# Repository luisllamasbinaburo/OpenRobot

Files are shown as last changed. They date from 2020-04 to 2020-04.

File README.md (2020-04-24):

# OpenRobot

OpenRobot is an Open Hardware PCB based on Arduino Nano, especially designed for teaching technology

Once assembled, you can use make multiple projects and robots without welding, just adding or removing components in the dupont headers.

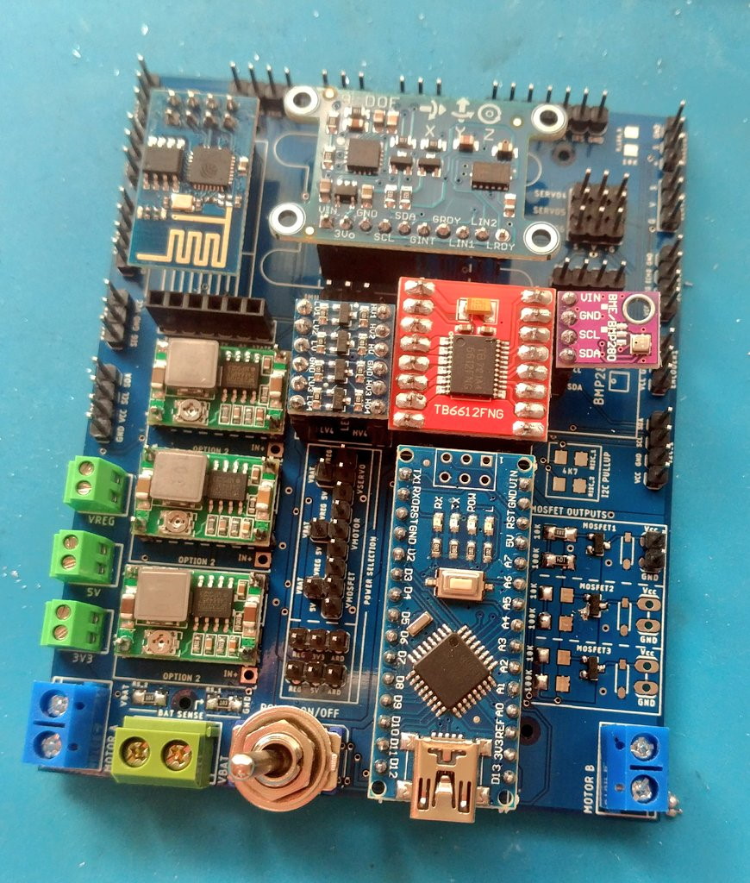
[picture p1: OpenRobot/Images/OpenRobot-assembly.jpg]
Assembly


OpenRobot is compatible with a huge number of modules thanks to the multiple outputs. 
Also, is compatible with several DC Converters, and differents IMUs (MPU6050, MPU9050/9250 and L3GD20)

## What can I make with OpenRobot?
Almost any Arduino project you can ever imagine! 

Some of them,
- DC Motors Robot, like obstacle avoider (ultrasonic or Sharp), line follower, self-balancing bot...
- Servo Motor Robot, like 2-DOF Tower, 6-DOF Arms...
- Mosfet output for high current proyects (LED, electromagnets, water pumps)
- Bluetooth projects (HC-05/HC-06), like Android or PC communication, beacons...
- WiFi projects (ESP01), like controlling from Web, MQTT datalogger...
- Temperature, pressure, humidity weather station with BME280
- Any other project, thanks to the multiple available outputs!

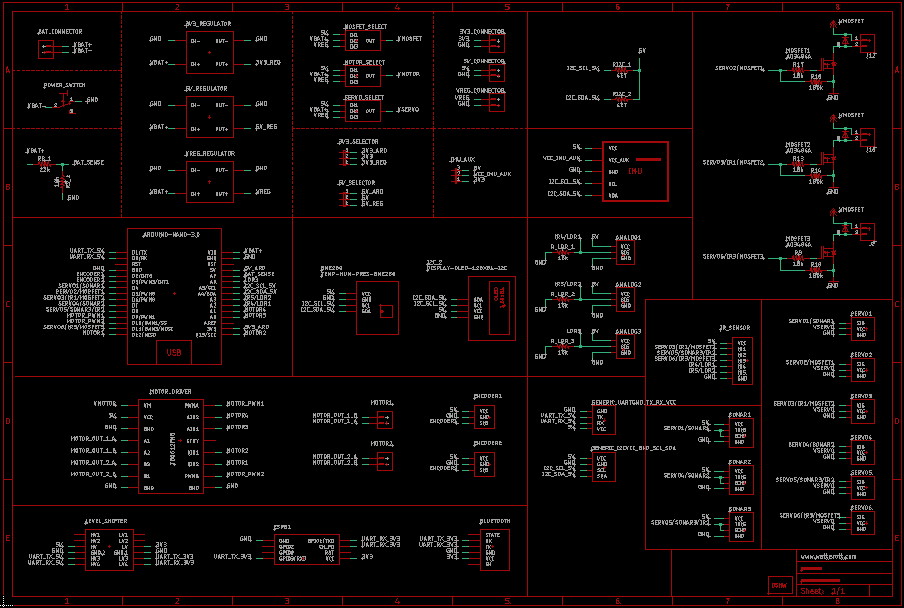
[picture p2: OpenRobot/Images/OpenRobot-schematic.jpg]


## Connectors
A lot of connectos availble, so you can customicce OpenRobot to you project requirement

- 2x DC Motor
- 2x Encoder
- Aux Output 3V3, 5V, Vreg
- 2x I2C 5V + 1x I2C 3V3
- 3x Ultrasonic Sensor
- 3x Analog Input (with optional smd resistor)
- 6x Servo
- 5x IR Sensor
- 3x Mosfet
 
 But, I you wany, can also use any of this output as a GPIO.

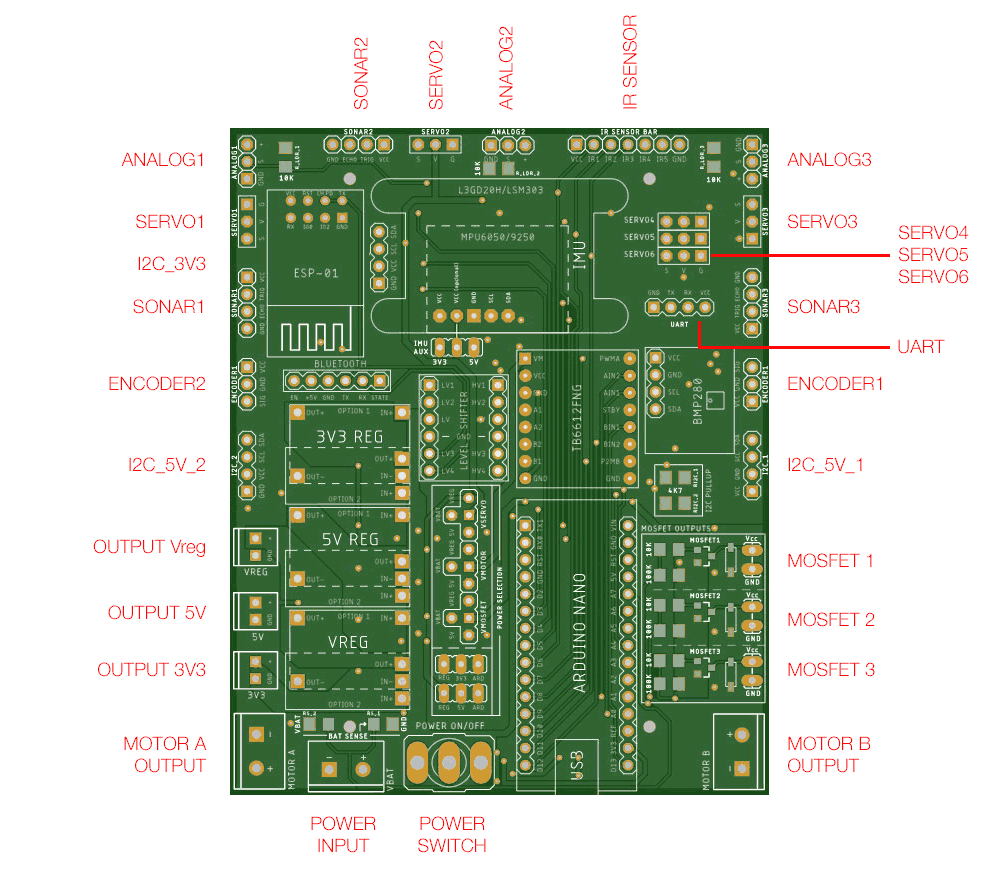
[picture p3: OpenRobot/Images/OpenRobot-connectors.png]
OpenRobot Connectors


## Pinout
Of course, not all the components and outputs are available at the same time, due to Arduino Nano pins numbers.

You have to choose which of this components your project requires. But posibilities are almost ilimited!

This is the pinout of OpenRobot

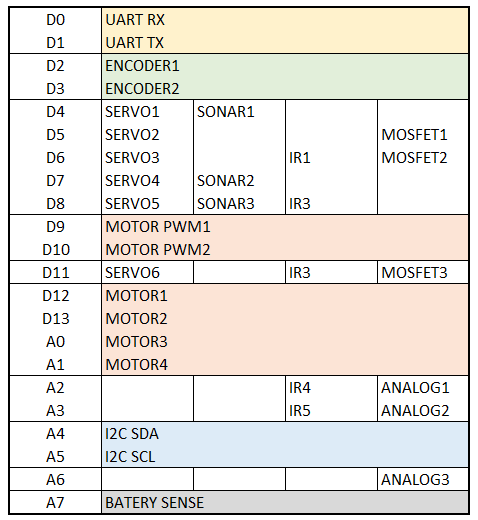
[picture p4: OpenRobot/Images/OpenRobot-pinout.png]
Pinout


## Components
OpenRobot allows you to mount several modules to your projects,
- Motor Driver TB6612FNG
- IMU (compatible with several IMUs)
- Temperature/Pressure/Humidity (BMP280/BME280)
- Level shifter (required to use Bluetooth or ESP01)
- Blueooth ESP01
- Bluetooth HC-04/05/06

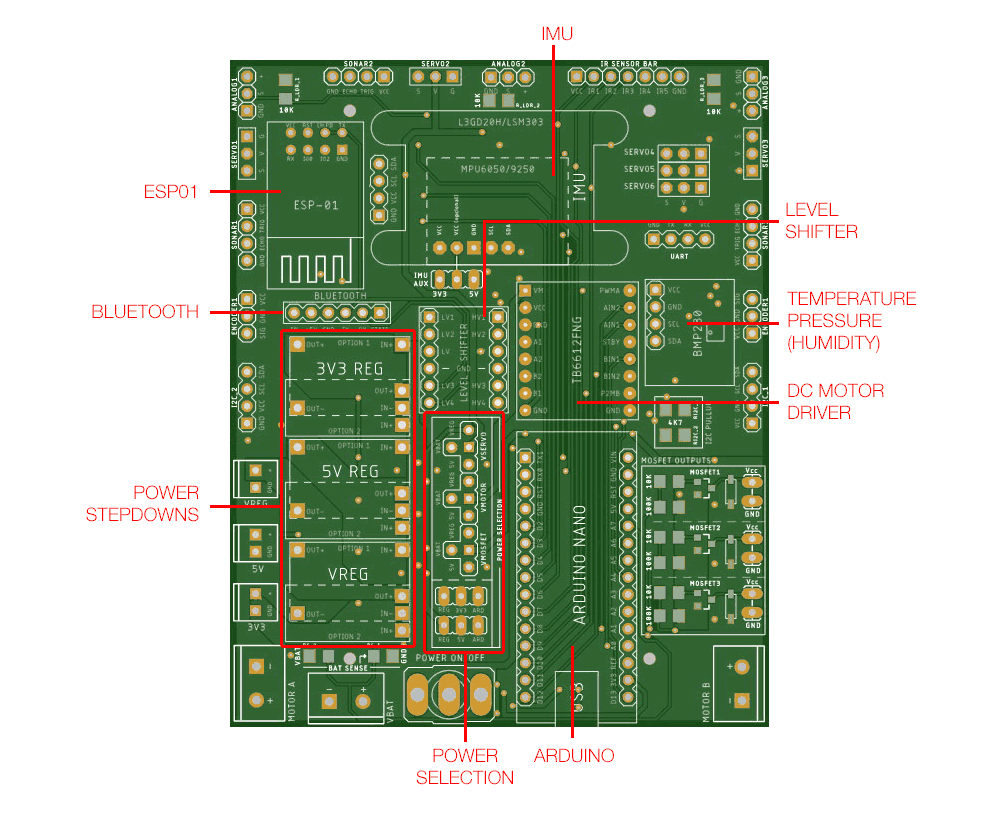
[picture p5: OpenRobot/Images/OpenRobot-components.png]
Components


But you can add a lot of modules thanks to the 3V3 and 5V I2C and UART.

## Powering
Powering is one of the most important point in any project. OpenRobot allow a simple but flexible power management in the proyect
- Power Switch 
- Up to 3 DC Converters (5V, 3V3, +1 Vreg)
- Power selector to select wich components (DC Motors, servo, Mosfet) are powering with each DC converter
- Posible to by-pass DC Converters and powering through Nano regulators (just in low-power and simple projects)
- Battery sense (optional)

### DC Converters
OpenRobot is compatible with two different DC Converters modules.

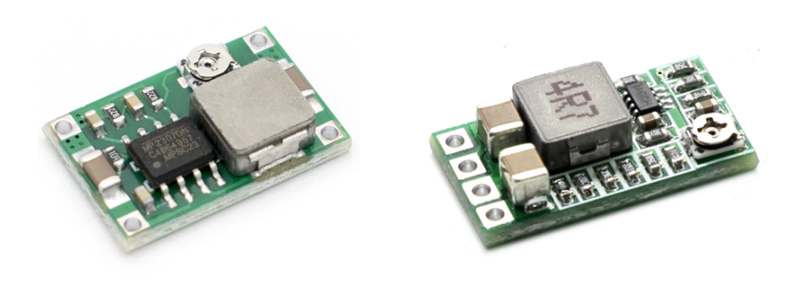
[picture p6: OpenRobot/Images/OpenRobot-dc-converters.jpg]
OpenRobot DC Converters


Just assembly in the right position for you DC Converter model.
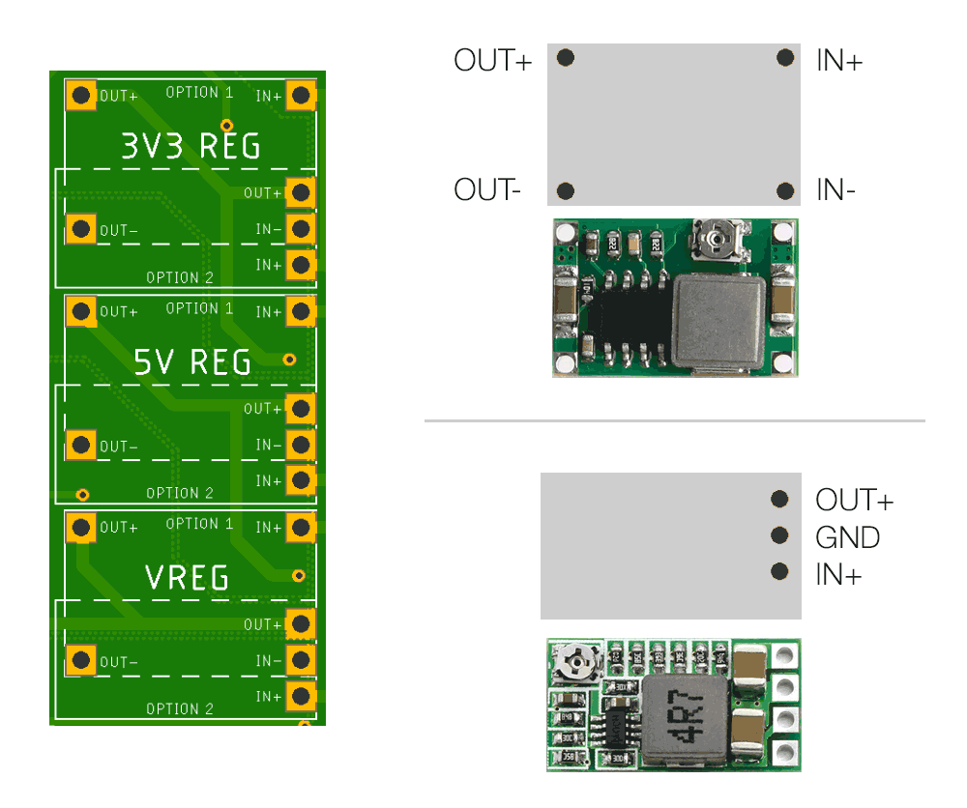
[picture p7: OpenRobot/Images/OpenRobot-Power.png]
OpenRobot Power


### Power selection
Powering selection to device are make using dupong jumper connections.
Outputs to:
- Servo
- DC Motors
- Mosfet

Can be connected to:
- Vregulated
- 5V
- Vbatery

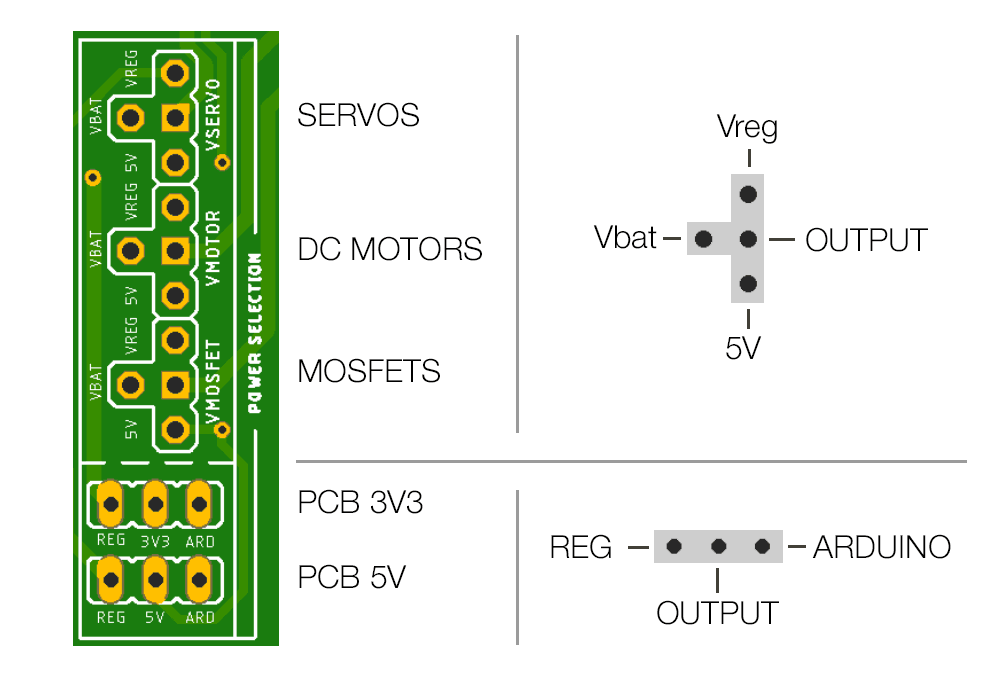
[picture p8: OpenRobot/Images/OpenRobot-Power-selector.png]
OpenRobot Powering


Aditionally, you can completely by-pass DC converters, and use Arduino regulators for 3V3 and/or 5V PCB rails, thus removing the need of installing DC Converters at all.

Only recommended in case of small / low power projects

## IMU
IMU is an important part of most Arduino projects. OpenRobot is compatible with a big number of IMUs, including the most populars. 

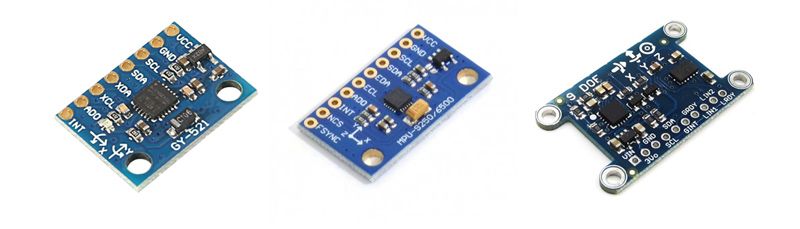
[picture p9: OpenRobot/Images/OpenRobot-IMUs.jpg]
OpenRobot IMUs


Just put your IMU in the right position. In some IMU modules you make need to use the Vcc optional pin to adapt powering to your IMU pinout.

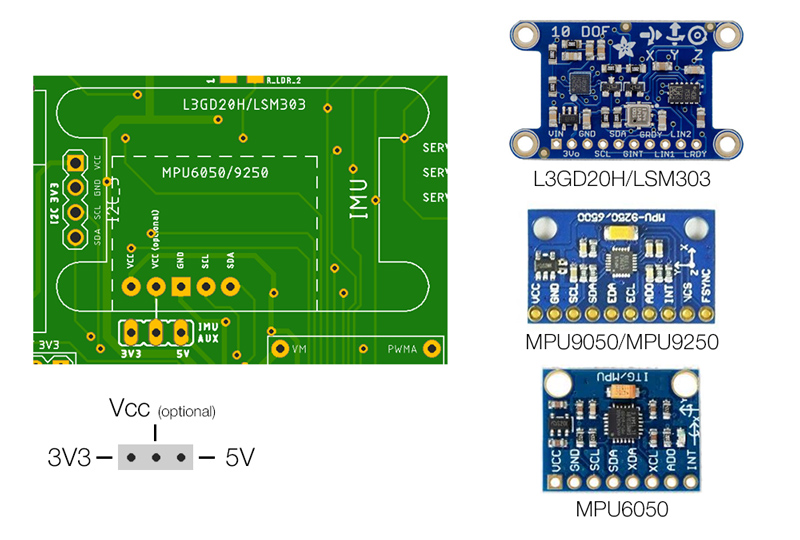
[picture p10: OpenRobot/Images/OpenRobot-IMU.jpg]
OpenRobot IMU


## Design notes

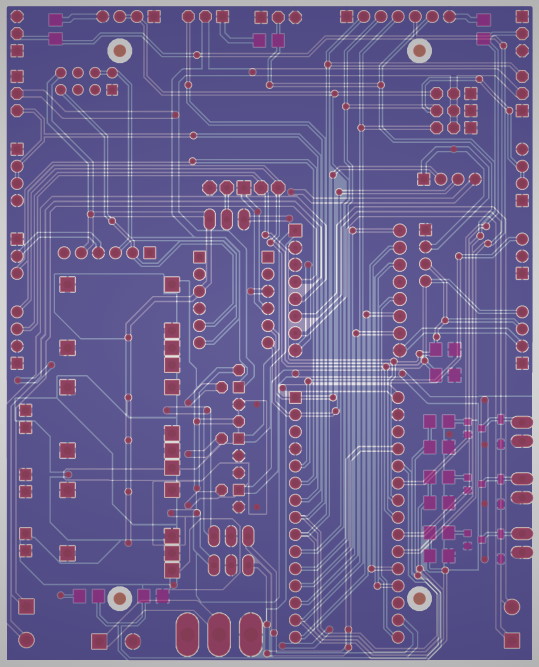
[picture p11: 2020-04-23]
OpenRobot/Images/OpenRobot-layers.jpg

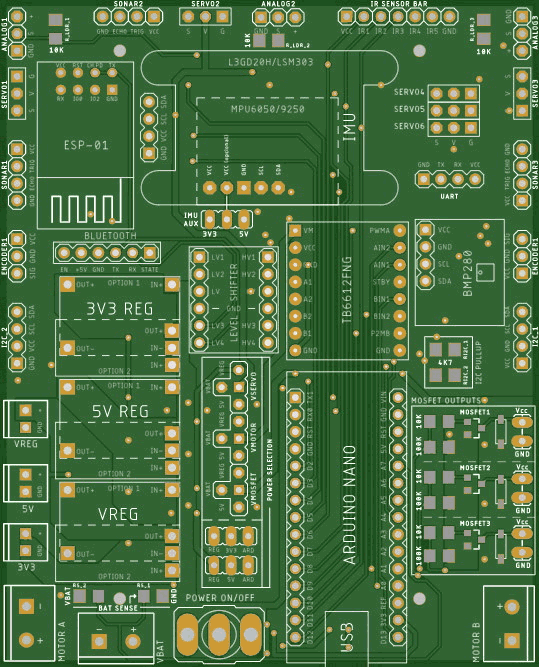
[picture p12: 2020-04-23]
OpenRobot/Images/OpenRobot-full.png

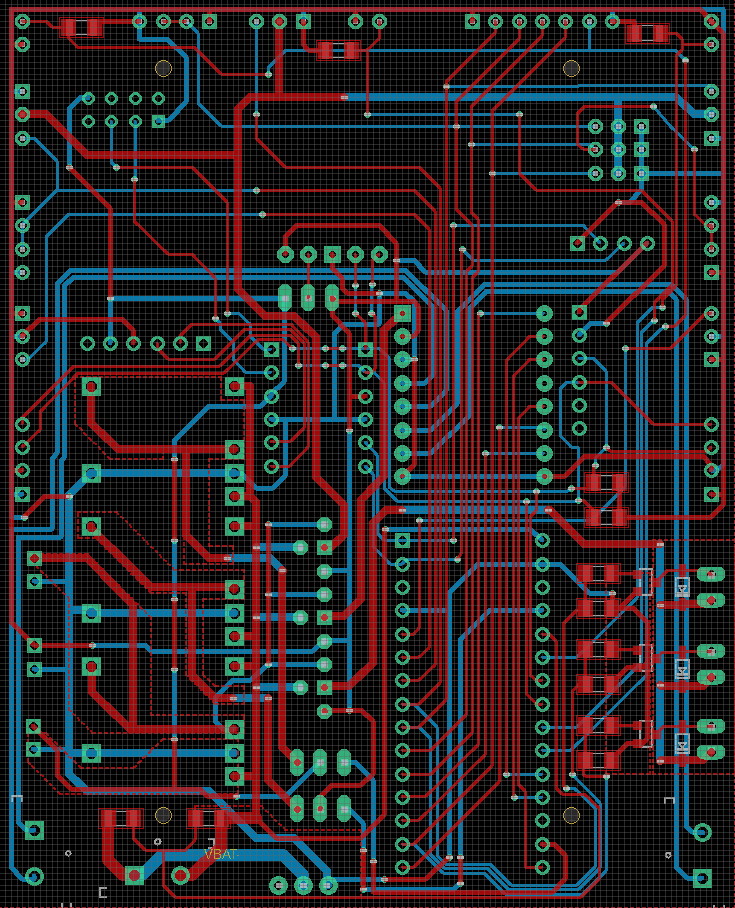
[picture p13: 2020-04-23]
OpenRobot/Images/OpenRobot-layout.jpg

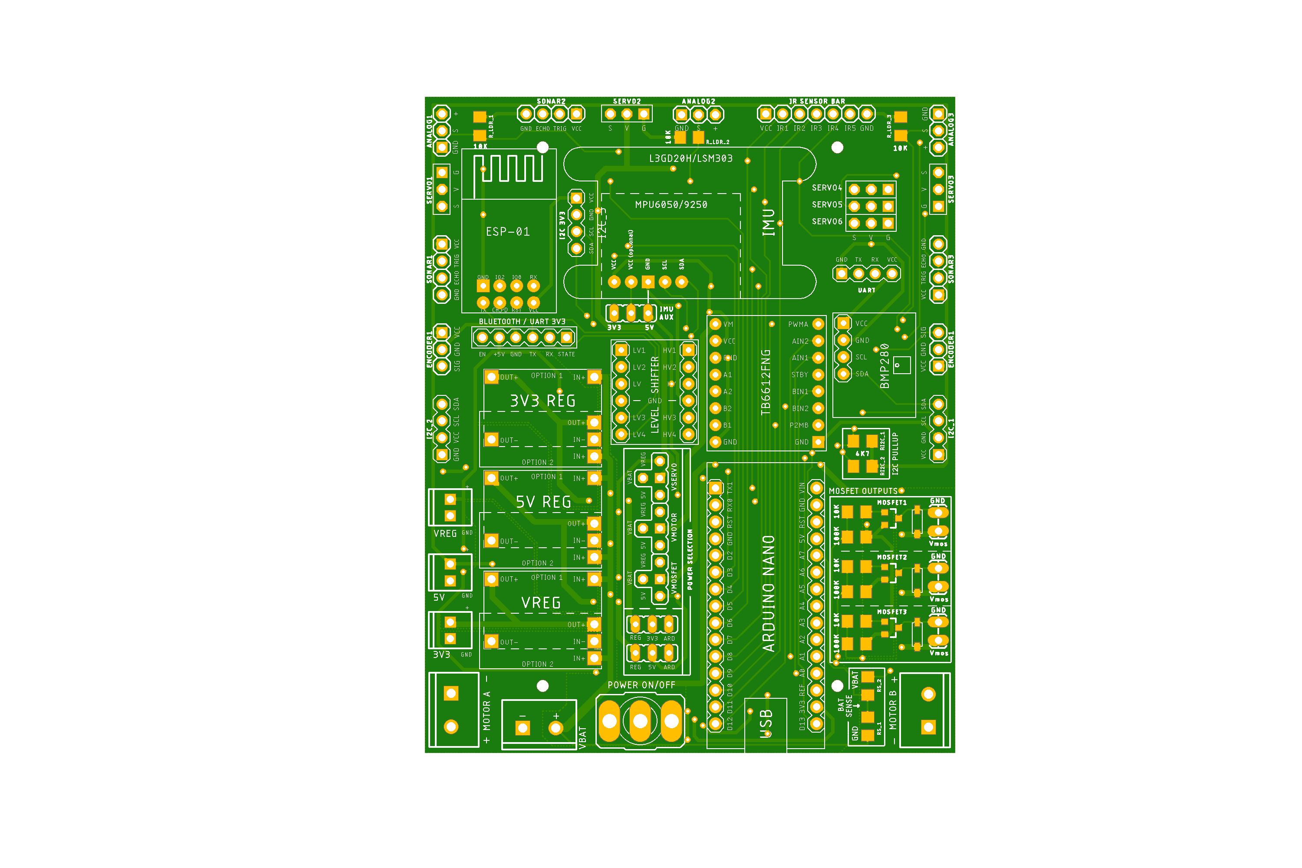
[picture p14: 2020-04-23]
OpenRobot/Images/MainBoard.png

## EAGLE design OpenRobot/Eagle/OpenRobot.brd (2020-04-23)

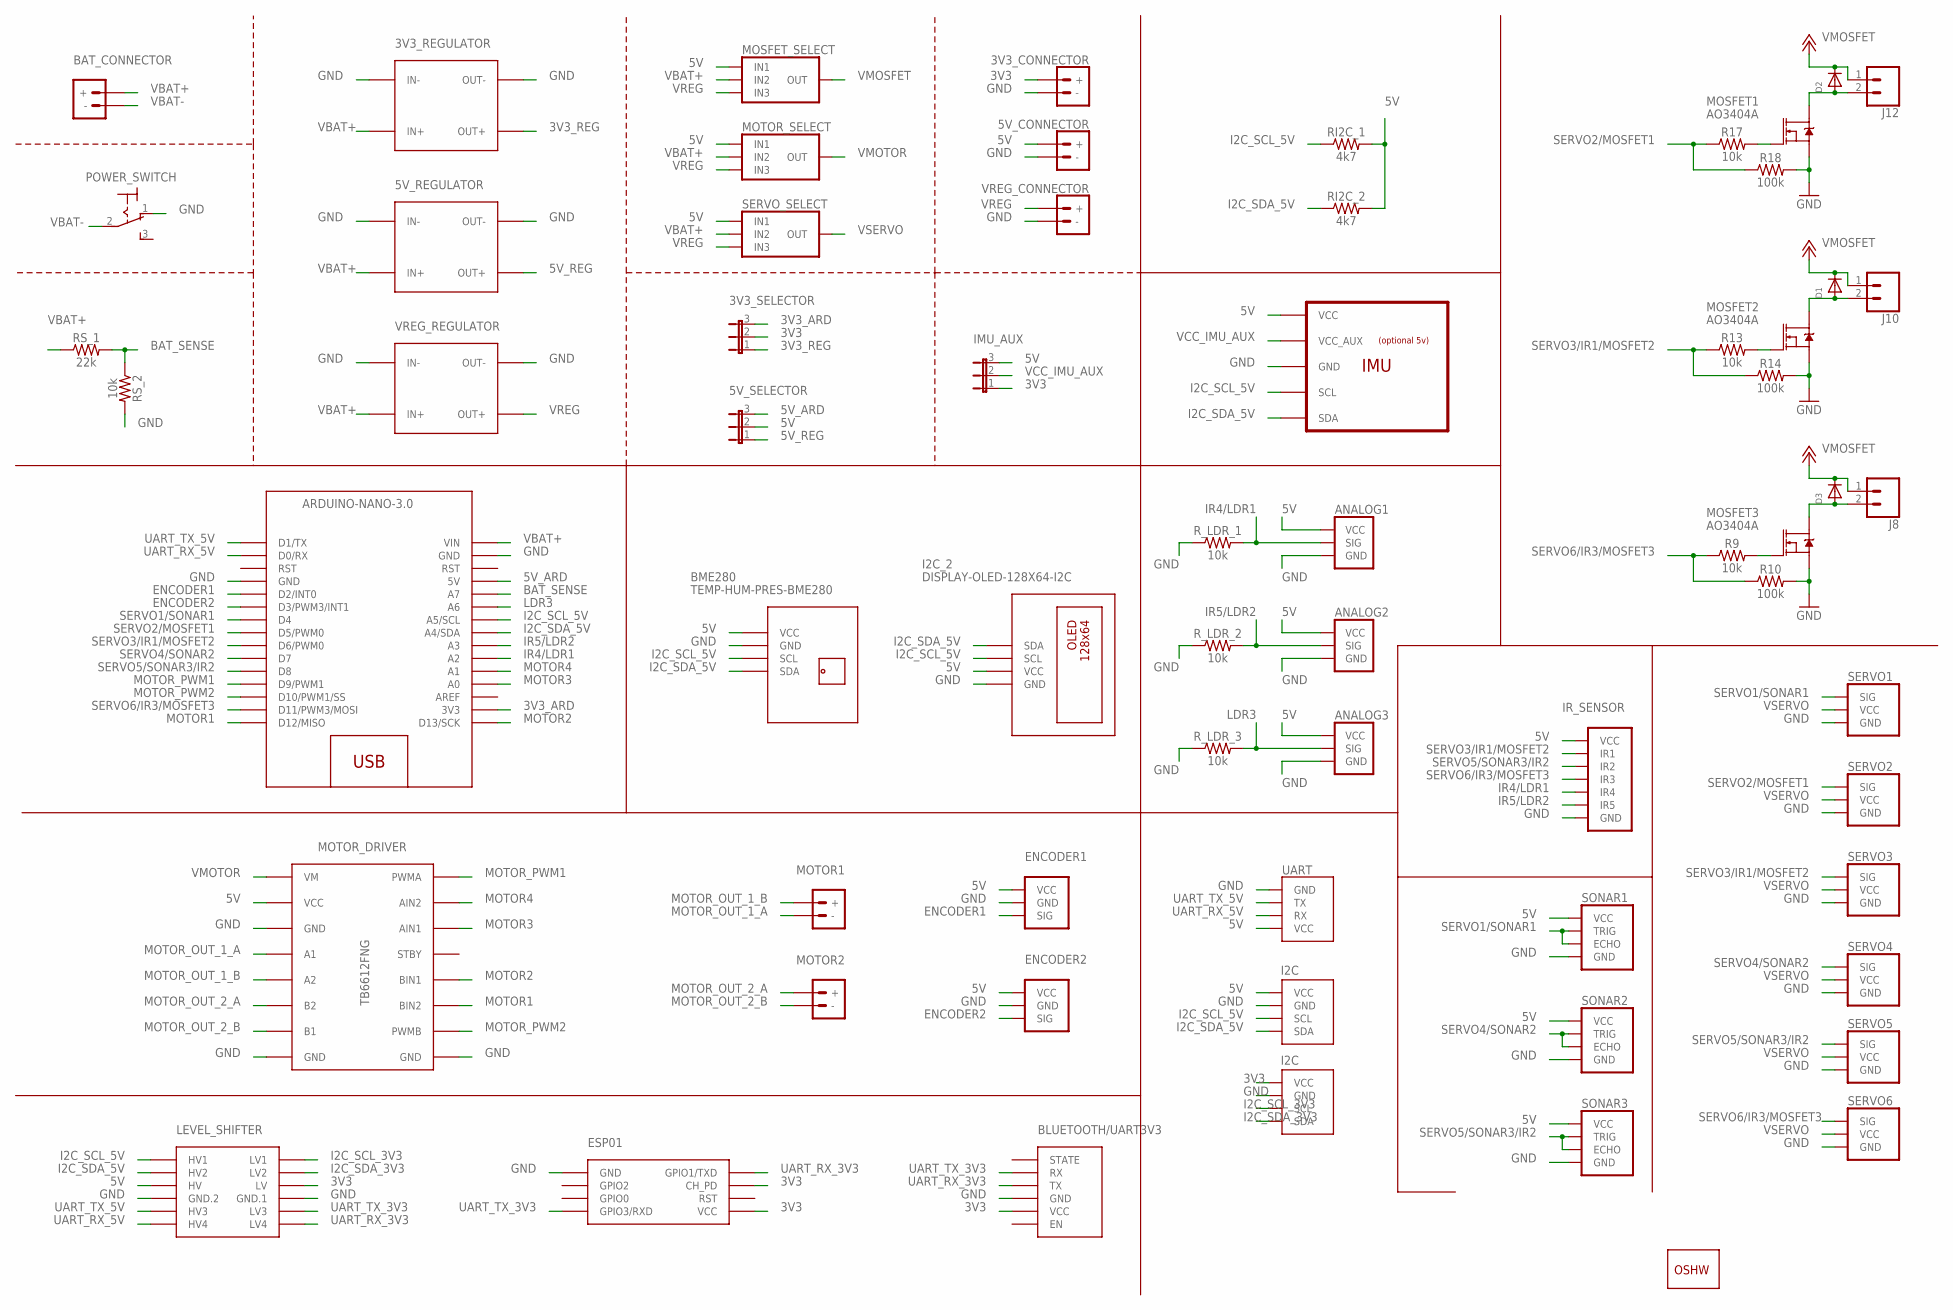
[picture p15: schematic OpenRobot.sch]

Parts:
3V3_CONNECTOR, 5V_CONNECTOR: MOTOR-TERMINAL2.54MM_SCREWTERM; 1X02_2.54_SCREWTERM
3V3_REGULATOR, 5V_REGULATOR: MINI-DC-STEP-DOWN-MP2307
3V3_SELECTOR, 5V_SELECTOR: 1; JP2
ANALOG1, ANALOG2, ANALOG3: LDR/OCT; LDR
ARDUINO_NANO1: ARDUINO-NANO-3.0
BAT_CONNECTOR: POWER-TERMINAL5MM; SCREWTERMINAL-5MM-2
BLUETOOTH/UART3V3: BLUETOOTH-HC-05
BME280: TEMP-HUM-PRES-BME280
D1, D2, D3: DIODESOD-123; SOD-123
ENCODER1, ENCODER2: ENCODER/OCT; ENCODER
GOLD_ORB_SM1: OSHWLOGO_GOLD_ORB_MED; OSHW1
I2C_1, I2C_3: I2C; I2C_VCC_GND_SCL_SDA
I2C_2: DISPLAY-OLED-128X64-I2C
IMU_AUX: 1; JP2
IR_SENSOR: IR-5/OCT; IR-5
J8, J10, J12: CONN_02LOCK_LONGPADS; 1X02_LOCK_LONGPADS
LEVEL_SHIFTER: LEVEL-SHIFTER-4CH
MOSFET1, MOSFET2, MOSFET3: AO3404A; SOT23-3
MOSFET_SELECT: JUMPER_3-1
MOTOR1, MOTOR2: MOTOR-TERMINAL5MM; SCREWTERMINAL-5MM-2
MOTOR_DRIVER: TB6612FNG
MOTOR_SELECT: JUMPER_3-1
POWER_SWITCH: LEVER-POWER-SWITCH; M9040P
R9, R13, R17: 10k; 1206
R10, R14, R18: 100k; 1206
RI2C_1, RI2C_2: 4k7; 1206
RS_1: 22k; 1206
RS_2: 10k; 1206
R_LDR_1, R_LDR_2, R_LDR_3: 10k; 1206
SERVO1, SERVO2, SERVO3, SERVO4, SERVO5, SERVO6: SERVOSERVO; SERVO
SERVO_SELECT: JUMPER_3-1
SONAR1, SONAR2, SONAR3: ULTRASONIC/OCT; ULTRASONIC
U1: IMU_6/9/10DOFMPU6050; IMU_6/9/10DOF
U$1: ESP01
UART: UART; GENERIC_UART
VREG_CONNECTOR: MOTOR-TERMINAL2.54MM_SCREWTERM; 1X02_2.54_SCREWTERM
VREG_REGULATOR: MINI-DC-STEP-DOWN-MP2307

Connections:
3V3: 3V3_CONNECTOR.+, 3V3_SELECTOR.2, BLUETOOTH/UART3V3.VCC, I2C_3.VCC, IMU_AUX.1, LEVEL_SHIFTER.J1.3 (LV), U$1.CH_PD, U$1.VCC
3V3_ARD: 3V3_SELECTOR.3, ARDUINO_NANO1.3V3
3V3_REG: 3V3_REGULATOR.OUT2.+ (OUT+), 3V3_REGULATOR.OUT+, 3V3_SELECTOR.1
5V: 5V_CONNECTOR.+, 5V_SELECTOR.2, ANALOG1.VCC, ANALOG2.VCC, ANALOG3.VCC, BME280.VCC, ENCODER1.VCC, ENCODER2.VCC, I2C_1.VCC, I2C_2.VCC, IMU_AUX.3, IR_SENSOR.VCC, LEVEL_SHIFTER.J2.3 (HV), MOSFET_SELECT.IN1, MOTOR_DRIVER.VCC, MOTOR_SELECT.IN1, RI2C_1.2, RI2C_2.2, SERVO_SELECT.IN1, SONAR1.VCC, SONAR2.VCC, SONAR3.VCC, U1.VCC, UART.VCC
5V_ARD: 5V_SELECTOR.3, ARDUINO_NANO1.5V
5V_REG: 5V_REGULATOR.OUT2.+ (OUT+), 5V_REGULATOR.OUT+, 5V_SELECTOR.1
BAT_SENSE: ARDUINO_NANO1.A7, RS_1.2, RS_2.1
ENCODER1: ARDUINO_NANO1.D2 (D2/INT0), ENCODER1.SIG
ENCODER2: ARDUINO_NANO1.D3 (D3/PWM3/INT1), ENCODER2.SIG
GND: 3V3_CONNECTOR.-, 3V3_REGULATOR.IN-, 3V3_REGULATOR.OUT-, 5V_CONNECTOR.-, 5V_REGULATOR.IN-, 5V_REGULATOR.OUT-, ANALOG1.GND, ANALOG2.GND, ANALOG3.GND, ARDUINO_NANO1.GND@1 (GND), ARDUINO_NANO1.GND@2 (GND), BLUETOOTH/UART3V3.GND, BME280.GND, ENCODER1.GND, ENCODER2.GND, I2C_1.GND, I2C_2.GND, I2C_3.GND, IR_SENSOR.GND, LEVEL_SHIFTER.J1.4 (GND.1), LEVEL_SHIFTER.J2.4 (GND.2), MOSFET1.2 (S), MOSFET2.2 (S), MOSFET3.2 (S), MOTOR_DRIVER.GND1 (GND), MOTOR_DRIVER.GND2 (GND), MOTOR_DRIVER.GND3 (GND), POWER_SWITCH.1 (O), R10.2, R14.2, R18.2, RS_2.2, R_LDR_1.1, R_LDR_2.1, R_LDR_3.1, SERVO1.GND, SERVO2.GND, SERVO3.GND, SERVO4.GND, SERVO5.GND, SERVO6.GND, SONAR1.GND, SONAR2.GND, SONAR3.GND, U1.GND, U$1.GND, UART.GND, VREG_CONNECTOR.-, VREG_REGULATOR.IN-, VREG_REGULATOR.OUT-
I2C_SCL_3V3: I2C_3.SCL, LEVEL_SHIFTER.J1.1 (LV1)
I2C_SCL_5V: ARDUINO_NANO1.A5 (A5/SCL), BME280.SCL, I2C_1.SCL, I2C_2.SCL, LEVEL_SHIFTER.J2.1 (HV1), RI2C_1.1, U1.SCL
I2C_SDA_3V3: I2C_3.SDA, LEVEL_SHIFTER.J1.2 (LV2)
I2C_SDA_5V: ARDUINO_NANO1.A4 (A4/SDA), BME280.SDA, I2C_1.SDA, I2C_2.SDA, LEVEL_SHIFTER.J2.2 (HV2), RI2C_2.1, U1.SDA
IR4/LDR1: ANALOG1.SIG, ARDUINO_NANO1.A2, IR_SENSOR.4 (IR4), R_LDR_1.2
IR5/LDR2: ANALOG2.SIG, ARDUINO_NANO1.A3, IR_SENSOR.5 (IR5), R_LDR_2.2
LDR3: ANALOG3.SIG, ARDUINO_NANO1.A6, R_LDR_3.2
MOTOR1: ARDUINO_NANO1.D12 (D12/MISO), MOTOR_DRIVER.BIN2
MOTOR2: ARDUINO_NANO1.D13 (D13/SCK), MOTOR_DRIVER.BIN1
MOTOR3: ARDUINO_NANO1.A0, MOTOR_DRIVER.AIN1
MOTOR4: ARDUINO_NANO1.A1, MOTOR_DRIVER.AIN2
MOTOR_OUT_1_A: MOTOR1.-, MOTOR_DRIVER.A1
MOTOR_OUT_1_B: MOTOR1.+, MOTOR_DRIVER.A2
MOTOR_OUT_2_A: MOTOR2.+, MOTOR_DRIVER.B2
MOTOR_OUT_2_B: MOTOR2.-, MOTOR_DRIVER.B1
MOTOR_PWM1: ARDUINO_NANO1.D9 (D9/PWM1), MOTOR_DRIVER.PWMA
MOTOR_PWM2: ARDUINO_NANO1.D10 (D10/PWM1/SS), MOTOR_DRIVER.PWMB
unnamed: MOSFET3.1 (G), R9.2
unnamed: D3.A, J8.2, MOSFET3.3 (D)
unnamed: MOSFET2.1 (G), R13.2
unnamed: D1.A, J10.2, MOSFET2.3 (D)
unnamed: MOSFET1.1 (G), R17.2
unnamed: D2.A, J12.2, MOSFET1.3 (D)
SERVO1/SONAR1: ARDUINO_NANO1.D4, SERVO1.SIG, SONAR1.ECHO, SONAR1.TRIG
SERVO2/MOSFET1: ARDUINO_NANO1.D5 (D5/PWM0), R17.1, R18.1, SERVO2.SIG
SERVO3/IR1/MOSFET2: ARDUINO_NANO1.D6 (D6/PWM0), IR_SENSOR.1 (IR1), R13.1, R14.1, SERVO3.SIG
SERVO4/SONAR2: ARDUINO_NANO1.D7, SERVO4.SIG, SONAR2.ECHO, SONAR2.TRIG
SERVO5/SONAR3/IR2: ARDUINO_NANO1.D8, IR_SENSOR.2 (IR2), SERVO5.SIG, SONAR3.ECHO, SONAR3.TRIG
SERVO6/IR3/MOSFET3: ARDUINO_NANO1.D11 (D11/PWM3/MOSI), IR_SENSOR.3 (IR3), R9.1, R10.1, SERVO6.SIG
UART_RX_3V3: BLUETOOTH/UART3V3.TX, LEVEL_SHIFTER.J1.6 (LV4), U$1.TX (GPIO1/TXD)
UART_RX_5V: ARDUINO_NANO1.RX0 (D0/RX), LEVEL_SHIFTER.J2.6 (HV4), UART.RX
UART_TX_3V3: BLUETOOTH/UART3V3.RX, LEVEL_SHIFTER.J1.5 (LV3), U$1.RX (GPIO3/RXD)
UART_TX_5V: ARDUINO_NANO1.TX1 (D1/TX), LEVEL_SHIFTER.J2.5 (HV3), UART.TX
VBAT+: 3V3_REGULATOR.IN+, 3V3_REGULATOR.IN.2+ (IN+), 5V_REGULATOR.IN+, 5V_REGULATOR.IN.2+ (IN+), ARDUINO_NANO1.VIN, BAT_CONNECTOR.+, MOSFET_SELECT.IN2, MOTOR_SELECT.IN2, RS_1.1, SERVO_SELECT.IN2, VREG_REGULATOR.IN+, VREG_REGULATOR.IN.2+ (IN+)
VBAT-: BAT_CONNECTOR.-, POWER_SWITCH.2
VCC_IMU_AUX: IMU_AUX.2, U1.VCC_AUX
VMOSFET: D1.C, D2.C, D3.C, J8.1, J10.1, J12.1, MOSFET_SELECT.OUT
VMOTOR: MOTOR_DRIVER.VM, MOTOR_SELECT.OUT
VREG: MOSFET_SELECT.IN3, MOTOR_SELECT.IN3, SERVO_SELECT.IN3, VREG_CONNECTOR.+, VREG_REGULATOR.OUT2.+ (OUT+), VREG_REGULATOR.OUT+
VSERVO: SERVO1.VCC, SERVO2.VCC, SERVO3.VCC, SERVO4.VCC, SERVO5.VCC, SERVO6.VCC, SERVO_SELECT.OUT

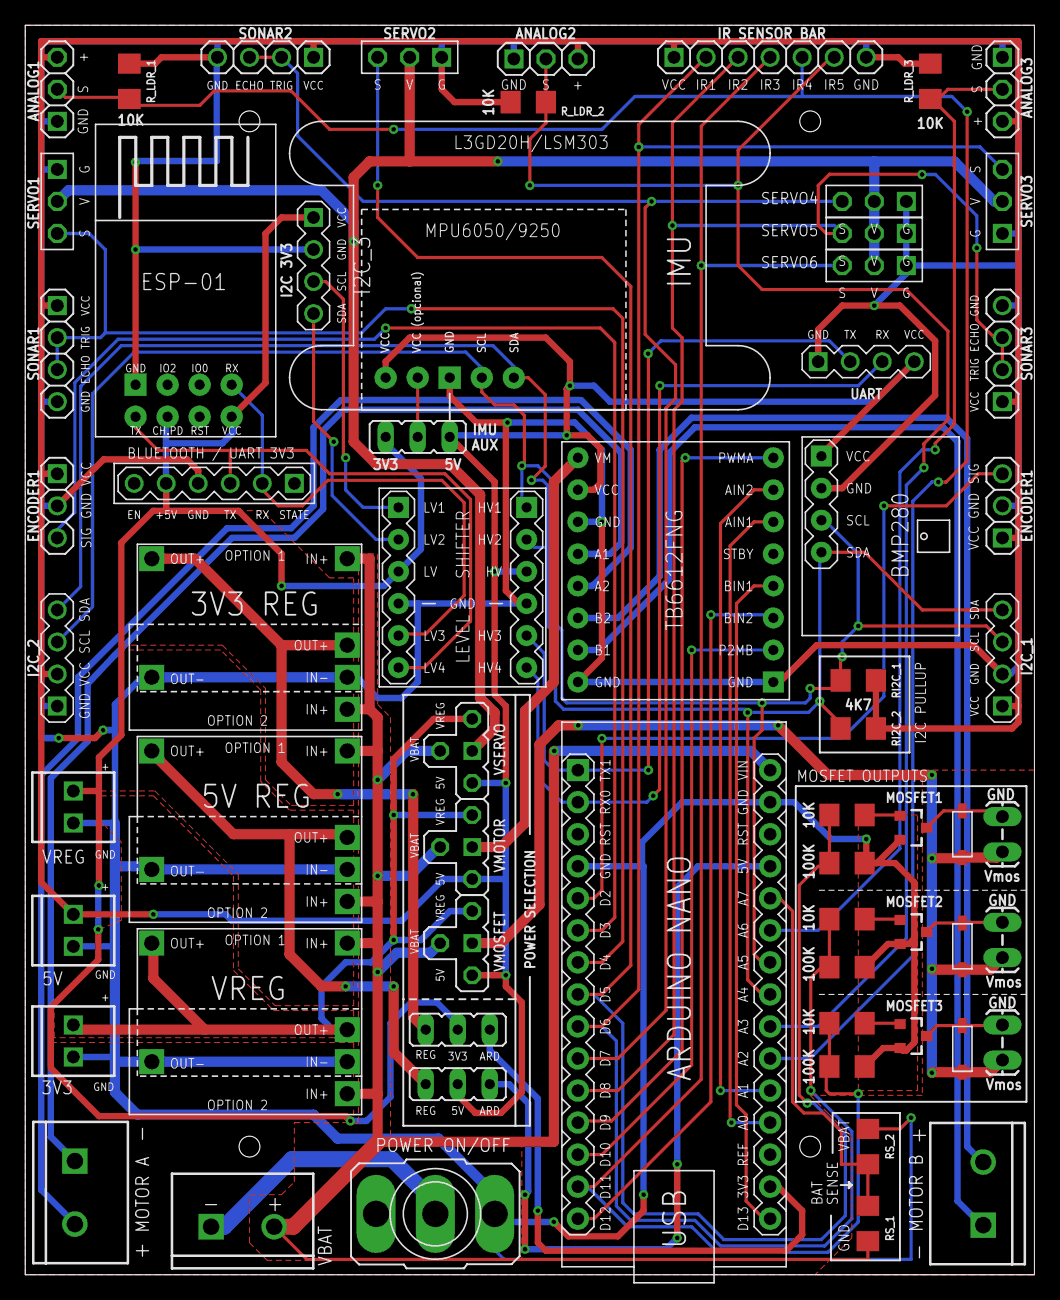
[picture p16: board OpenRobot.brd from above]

Board: 2 copper layers, 80.0 x 99.1 mm, 65 parts (1 on the bottom side), 50 nets.

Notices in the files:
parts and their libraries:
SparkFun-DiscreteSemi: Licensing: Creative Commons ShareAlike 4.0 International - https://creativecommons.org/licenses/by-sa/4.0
